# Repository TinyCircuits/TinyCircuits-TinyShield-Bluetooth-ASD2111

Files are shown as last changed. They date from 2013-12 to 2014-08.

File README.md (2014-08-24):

# TinyCircuits TinyShield Bluetooth Board
# ASD2111 Rev2

These are the design files for the TinyCircuits ASD2111 Rev 2 PCB.  This is a TinyShield board that has a Roving Networks RN42 Bluetooth 2.1 module, local power supply and level shifters to connect between the TinyDuino and the Bluetooth Module. 

Format is in Cadsoft Eagle format - Eagle version 6.2 was used for the original design.

For more infomation on this, check out the product page at Tiny-Circuits.com:  https://tiny-circuits.com/tiny-shield-bluetooth-163.html

#License:

Design by TinyCircuits.
All design files are released under the Creative Commons Attribution Share-Alike 3.0 License, see the following link for details: http://creativecommons.org/licenses/by-sa/3.0

All text above must be included in any redistribution or derived design

This project uses designs and concepts developed as part of the Arduino project and the LilyPad project.  The TinyCircuits design files themselves (schematics, PCB and libraries) are not directly derived from these works' design files and have been created new, however the concepts and basic architecture behind the TinyDuino and TinyLily products are derived and we thank the hard work of the organizations below for their contributions to open-source hardware:
  
Original Arduino Uno Design by Team Arduino

LilyPad Arduino Design by Leah Buechley and Sparkfun Electronics

Please support the open-source hardware community

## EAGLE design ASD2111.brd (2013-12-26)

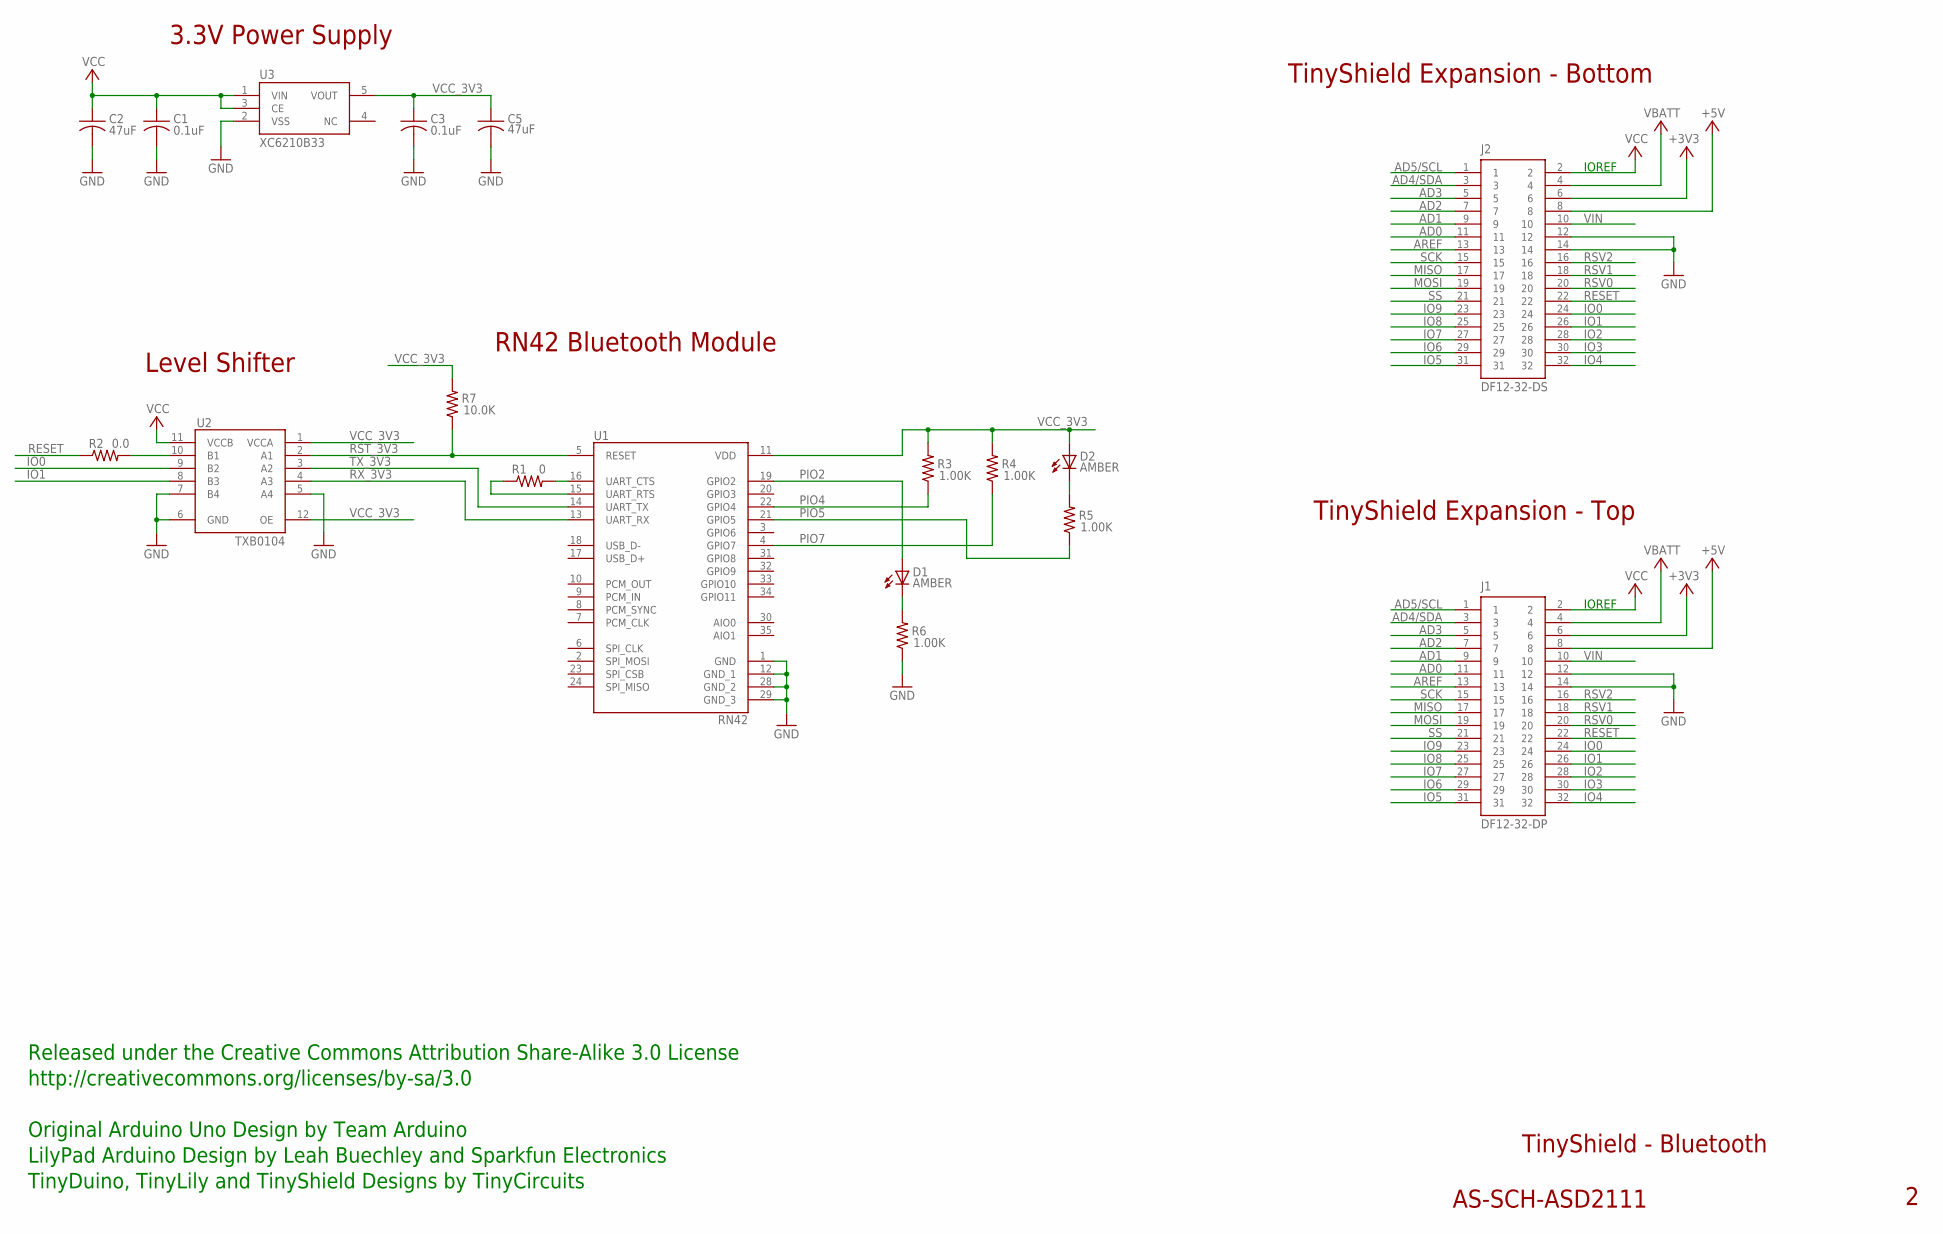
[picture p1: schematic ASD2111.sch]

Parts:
C1, C3: 0.1uF; C0402; PARTNO AS-ITM-00008
C2: 47uF; C1206; PARTNUM AS-ITM-00049
C5: 47uF; C1206
D1: AMBER; LNJ_LED
D2: AMBER; LNJ_LED; PARTNO AS-ITM-00026
J1: DF12-32-DP; PARTNO AS-ITM-00015
J2: DF12-32-DS; PARTNO AS-ITM-00012
R1: 0; 0402_SHORT
R2: 0.0; 0402
R3: 1.00K; 0402
R4, R5, R6: 1.00K; 0402; PARTNO AS-ITM-00003
R7: 10.0K; 0402
U1: RN42; RN42_BLUETOOTH_MODULE
U2: TXB0104; UQFN-12
U3: XC6210B33; SOT-25

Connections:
+3V3: J1.6, J2.6
+5V: J1.8, J2.8
AD0: J1.11, J2.11
AD1: J1.9, J2.9
AD2: J1.7, J2.7
AD3: J1.5, J2.5
AD4/SDA: J1.3, J2.3
AD5/SCL: J1.1, J2.1
AREF: J1.13, J2.13
GND: C1.2, C2.2, C3.2, C5.2, J1.12, J1.14, J2.12, J2.14, R6.1, U1.1 (GND), U1.12 (GND_1), U1.28 (GND_2), U1.29 (GND_3), U2.5 (A4), U2.6 (GND), U2.7 (B4), U3.2 (VSS)
IO0: J1.24, J2.24, U2.9 (B2)
IO1: J1.26, J2.26, U2.8 (B3)
IO2: J1.28, J2.28
IO3: J1.30, J2.30
IO4: J1.32, J2.32
IO5: J1.31, J2.31
IO6: J1.29, J2.29
IO7: J1.27, J2.27
IO8: J1.25, J2.25
IO9: J1.23, J2.23
MISO: J1.17, J2.17
MOSI: J1.19, J2.19
unnamed: R1.2, U1.16 (UART_CTS)
unnamed: R1.1, U1.15 (UART_RTS)
unnamed: R2.2, U2.10 (B1)
unnamed: D1.C, R6.2
unnamed: D2.C, R5.2
PIO2: D1.A, U1.19 (GPIO2)
PIO4: R3.1, U1.22 (GPIO4)
PIO5: R5.1, U1.21 (GPIO5)
PIO7: R4.1, U1.4 (GPIO7)
RESET: J1.22, J2.22, R2.1
RST_3V3: R7.1, U1.5 (RESET), U2.2 (A1)
RSV0: J1.20, J2.20
RSV1: J1.18, J2.18
RSV2: J1.16, J2.16
RX_3V3: U1.13 (UART_RX), U2.4 (A3)
SCK: J1.15, J2.15
SS: J1.21, J2.21
TX_3V3: U1.14 (UART_TX), U2.3 (A2)
VBATT: J1.4, J2.4
VCC: C1.1, C2.1, J1.2, J2.2, U2.11 (VCCB), U3.1 (VIN), U3.3 (CE)
VCC_3V3: C3.1, C5.1, D2.A, R3.2, R4.2, R7.2, U1.11 (VDD), U2.1 (VCCA), U2.12 (OE), U3.5 (VOUT)
VIN: J1.10, J2.10

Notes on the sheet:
TinyShield Expansion - Bottom
TinyShield - Bluetooth
AS-SCH-ASD2111
TinyShield Expansion - Top
IOREF
Released under the Creative Commons Attribution Share-Alike 3.0 License
http://creativecommons.org/licenses/by-sa/3.0
LilyPad Arduino Design by Leah Buechley and Sparkfun Electronics
TinyDuino, TinyLily and TinyShield Designs by TinyCircuits
Original Arduino Uno Design by Team Arduino
3.3V Power Supply
RN42 Bluetooth Module
Level Shifter

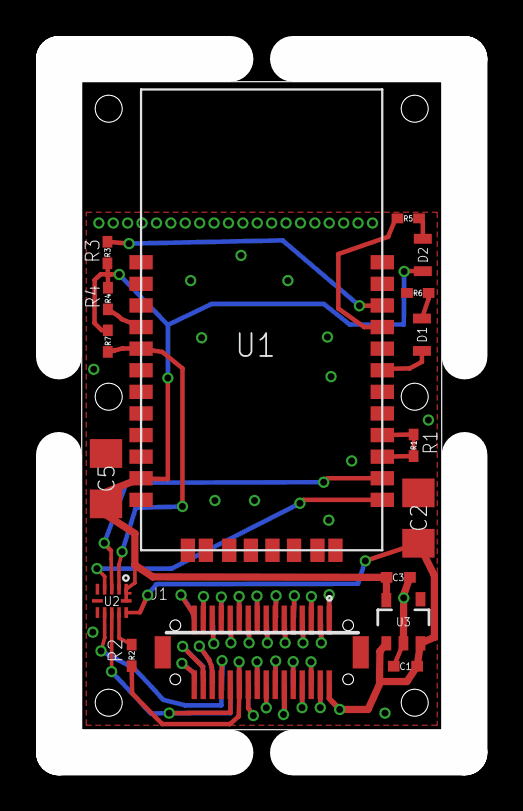
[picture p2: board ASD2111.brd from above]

Board: 2 copper layers, 20.0 x 36.0 mm, 19 parts (1 on the bottom side), 44 nets.

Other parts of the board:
U$1: DOCFIELD-TINYCIRCUITS-PCB
